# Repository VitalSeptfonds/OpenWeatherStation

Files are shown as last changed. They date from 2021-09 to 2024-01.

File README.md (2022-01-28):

# OpenWeatherStation

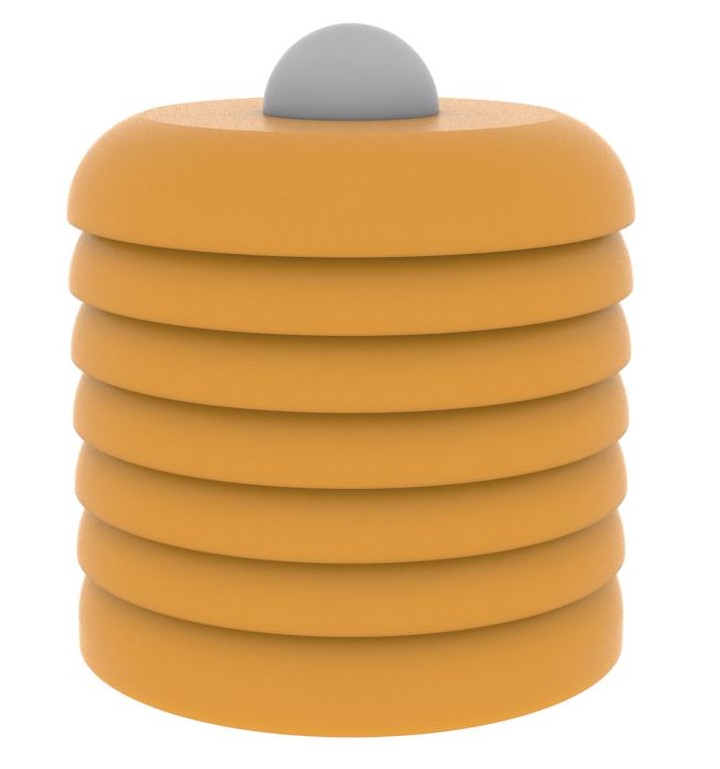
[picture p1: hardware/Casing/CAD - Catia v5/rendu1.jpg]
Test Image


## The Project
The main goal is to create an Open Weather Station based on STM32.
This weather station will give access to real time data through an Web API.

### Main Functionality 
- POE : Power Over Ethernet
- 3D printable 
- Ingress Protection : IP33
  - Protected from tools and wires greater than 2.5 millimeters
  - Protected from water spray less than 60 degrees from vertical
- Real time data
- Sensors :
  - Temperature
  - Humidity
  - Pressure
  - Light

## API
### Request
`GET /get_data/`

Return Real Time Data

### Response

    {
      "time" : "01/01/01 00:00:00",
      "data" :
        {
          "temperature" : 20.00,
          "humidity" : 50,
          "pressure" : 1013,
          "light" : 3000
        }

    }

## Error handling

Error responses should include a common HTTP status code, message for the developer, message for the end-user (when appropriate), internal error code

    {
      "error" :
        {
          "status" : 400,
          "errorCode" : "444444",
          "errorMessage" : "Verbose, plain language description of the problem. Provide developers
           suggestions about how to solve their problems here",
          "userMessage" : "This is a message that can be passed along to end-users, if needed."
         }
    }

Use three simple, common response codes :

* 400 - Bad Request
* 404 - Not Found
* 500 - Internal Server Error

## Links
* [Hardware](hardware/readme.md)
* [Software](software/readme.md)

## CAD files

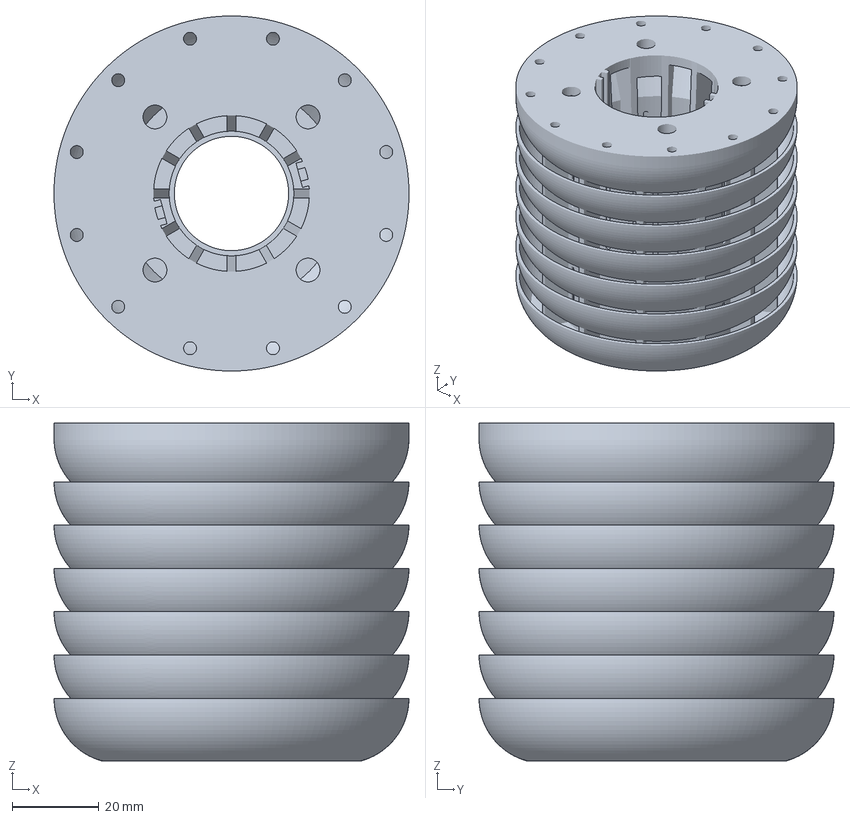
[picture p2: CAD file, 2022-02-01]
hardware/Casing/3D Printing Setup/MainCase.3mf
82.0 x 82.0 x 78.0 mm

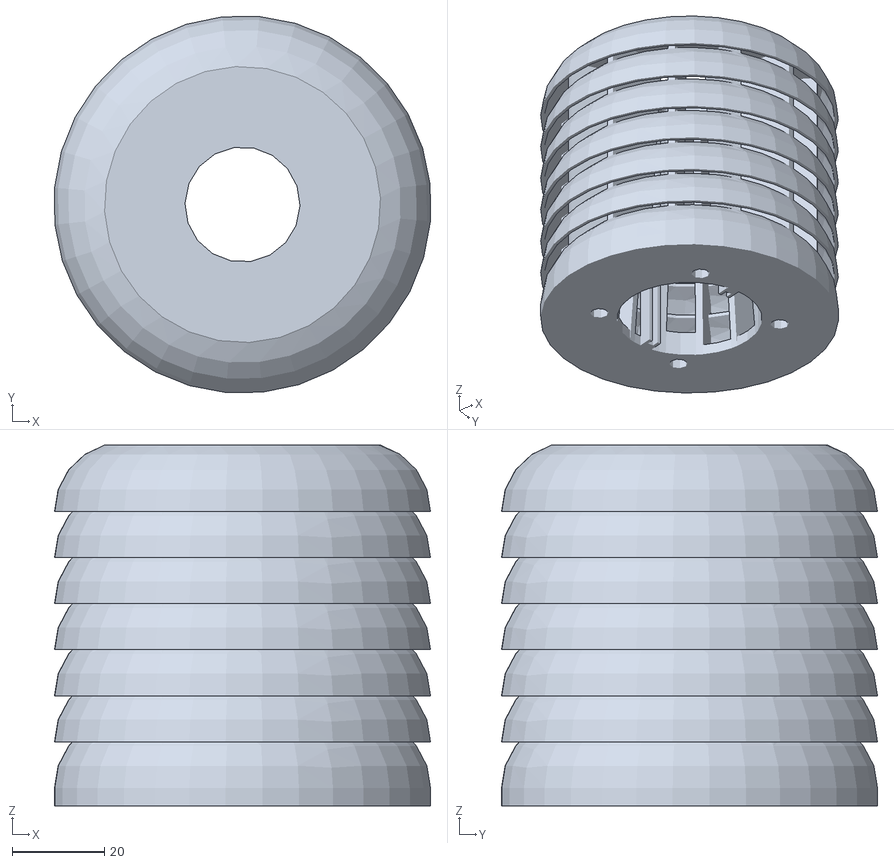
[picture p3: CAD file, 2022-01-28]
hardware/Casing/STL/MainCase.stl
81.7 x 81.7 x 78.4

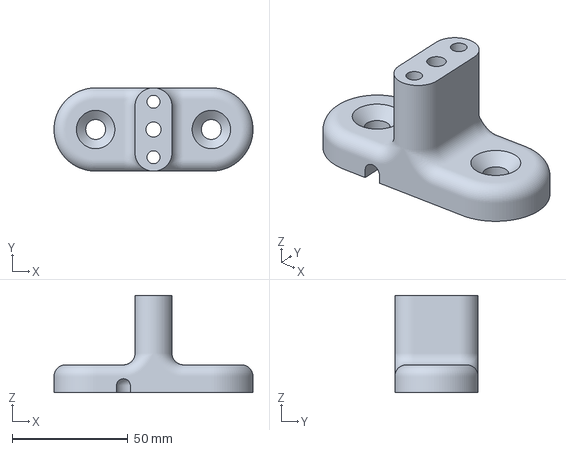
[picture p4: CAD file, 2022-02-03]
hardware/Casing/3D Printing Setup/wall_arm.3mf
86.0 x 36.0 x 42.0 mm

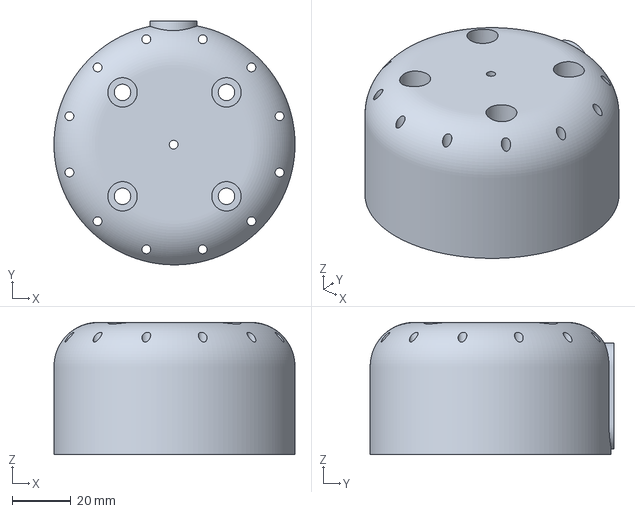
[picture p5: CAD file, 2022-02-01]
hardware/Casing/3D Printing Setup/Wall_Support.3mf
82.0 x 82.9 x 45.0 mm

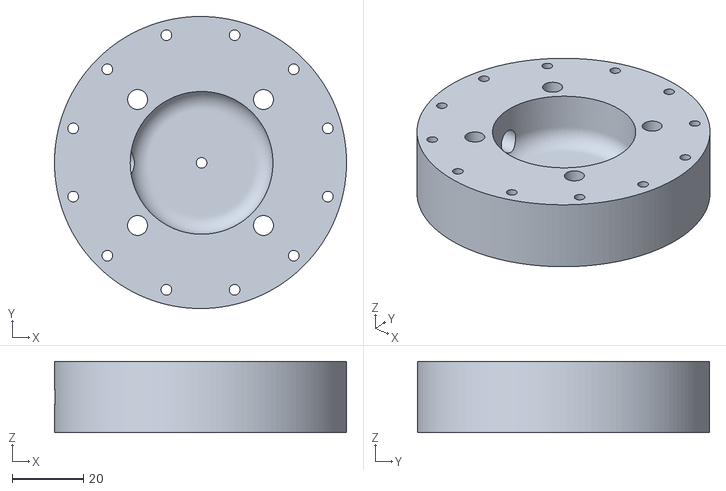
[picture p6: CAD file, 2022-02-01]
hardware/Casing/STL/socle.stl
82.0 x 82.0 x 20.0

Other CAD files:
hardware/Casing/STL/wall_arm.stl
hardware/Casing/3D Printing Setup/socle.3mf
hardware/Casing/STL/Wall_Support.stl
hardware/Casing/CAD - Catia v5/BH1750.CATPart
hardware/Casing/CAD - Catia v5/MainAssembly.CATProduct
hardware/Casing/CAD - Catia v5/MainCase.CATPart
hardware/Casing/CAD - Catia v5/PCB.CATPart
hardware/Casing/CAD - Catia v5/Wall_Support.CATPart
hardware/Casing/CAD - Catia v5/socle.CATPart
hardware/Casing/CAD - Catia v5/wall_arm.CATPart

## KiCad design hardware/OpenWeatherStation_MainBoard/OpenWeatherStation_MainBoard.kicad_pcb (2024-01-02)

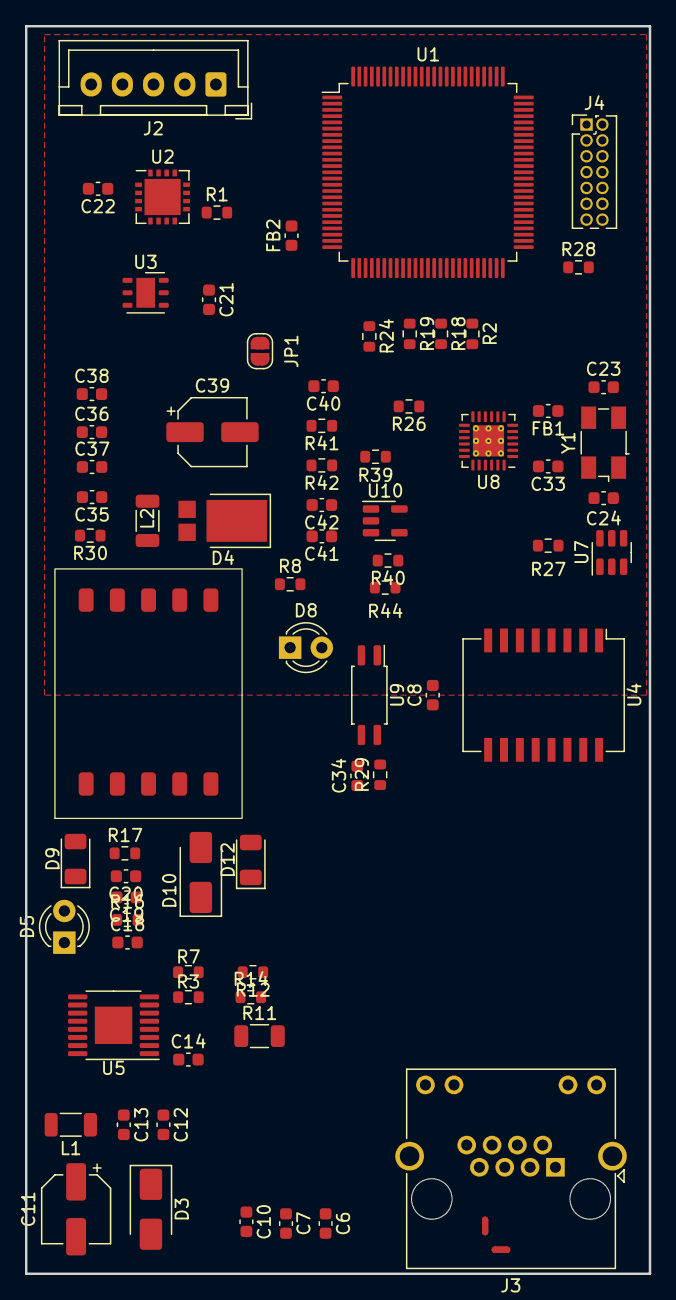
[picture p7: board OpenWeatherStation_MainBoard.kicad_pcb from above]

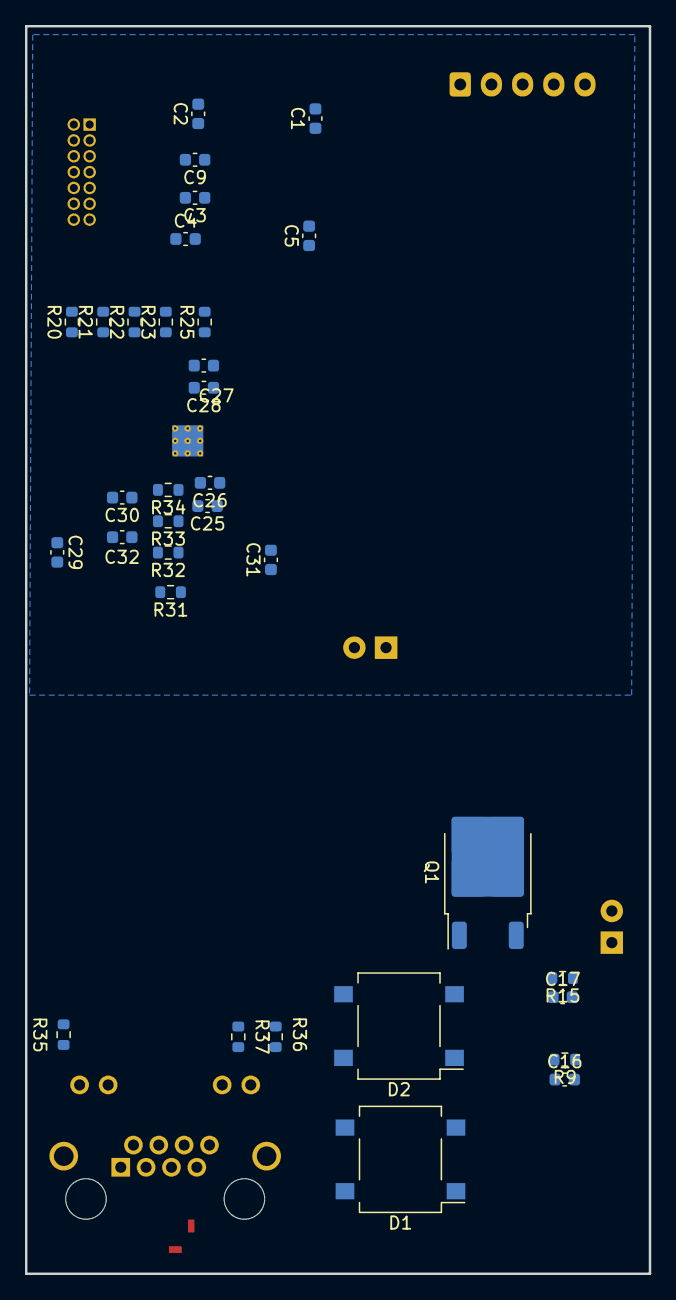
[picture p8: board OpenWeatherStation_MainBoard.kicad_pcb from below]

Board: 2 copper layers, 50.0 x 100.0 mm, 111 parts (33 on the bottom side), 85 nets, no tracks yet.

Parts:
C1, C2, C3, C4, C5, C9, C10, C12, C13, C16, C19, C21, C22, C25, C28, C29, C30, C31, C32: 100nF; C_0603_1608Metric
C6, C14: 1nF; C_0603_1608Metric
C7, C20, C26, C34, C40, C41: 1uF; C_0603_1608Metric
C8: 2.2nF; C_0603_1608Metric
C11: 22uF; CP_Elec_5x3
C17, C18, C27: 470pF; C_0603_1608Metric
C23, C24: 30pF; C_0603_1608Metric
C33: 10uF; C_0603_1608Metric
C35: 560pF; C_0603_1608Metric
C36, C37, C38: 22uF; C_0603_1608Metric
C39: 330uF; CP_Elec_5x3
C42: 22nF; C_0603_1608Metric
D1, D2: DF01S1; Diode_Bridge_OnSemi_SDIP-4L
D3, D10: SMAJ58A; D_SMA
D4: D_Schottky; D_PowerDI-5
D5, D8: LED; LED_D3.0mm
D9, D12: D_Schottky; D_1206_3216Metric
FB1, FB2: FerriteBead; C_0603_1608Metric
J2: Conn_01x05_Pin; JST_XH_B5B-XH-A_1x05_P2.50mm_Vertical
J3: RJ45_LED_Shielded; RJ45_Amphenol_RJHSE538X
J4: Conn_02x07_Odd_Even; PinHeader_2x07_P1.27mm_Vertical
JP1: SolderJumper_2_Open; SolderJumper-2_P1.3mm_Open_RoundedPad1.0x1.5mm
L1, L2: L; L_1206_3216Metric
NT1, NT2, NT3, NT4: NetTie_2; NetTie-2_SMD_Pad0.5mm
Q1: Q_NMOS_GDS; TO-252-2
R1, R8: 1k; R_0603_1608Metric
R2, R18, R19, R24: 33R; R_0603_1608Metric
R3: 158R; R_0603_1608Metric
R7: 22k; R_0603_1608Metric
R9: 124k; R_0603_1608Metric
R11: 0.33R; R_1206_3216Metric
R12: 0.33R; R_0603_1608Metric
R14, R20, R21, R22, R25, R26, R29, R37: 10k; R_0603_1608Metric
R15, R28: 100R; R_0603_1608Metric
R16: 4k7; R_0603_1608Metric
R17, R41: 10R; R_0603_1608Metric
R23: 1k5; R_0603_1608Metric
R27: 12k1; R_0603_1608Metric
R30: 4R7; R_0603_1608Metric
R31, R32, R33, R34: 50R; R_0603_1608Metric
R35, R36: 270R; R_0603_1608Metric
R39: 21k; R_0603_1608Metric
R40: 12k4; R_0603_1608Metric
R42: 390R; R_0603_1608Metric
R44: 3k3; R_0603_1608Metric
U1: STM32F107VCTx; LQFP-100_14x14mm_P0.5mm
U2: FXPS7115D4; Panasonic_HQFN-16-1EP_4x4mm_P0.65mm_EP2.9x2.9mm
U3: HTU21D; DFN-6-1EP_3x3mm_P1mm_EP1.5x2.4mm
U4: Transformer_Ethernet_Wuerth_749013011A
U5: PM8800A; HTSSOP-16-1EP_4.4x5mm_P0.65mm_EP3x3mm
U6: POE13P-33L; SM13117EL
U7: USBLC6-4SC6; SOT-23-6
U8: LAN8742A; VQFN-24-1EP_4x4mm_P0.5mm_EP2.5x2.5mm_ThermalVias
U9: TCMT1107; SOP-4_4.4x2.6mm_P1.27mm
U10: TL431DBV; SOT-23-5
Y1: Crystal; Crystal_SMD_Abracon_ABM3B-4Pin_5.0x3.2mm

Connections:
+3.3VA: FB2.2, U1.21 (VREF+), U1.22 (VDDA)
+3V3: C1.1, C2.1, C3.1, C4.1, C5.1, C9.1, C21.1, C22.1, C28.1, FB1.2, FB2.1, J2.1, J4.3, R1.1, R20.2, R21.2, R22.2, R23.2, R25.2, U1.6 (VBAT), U1.11 (VDD), U1.28 (VDD), U1.50 (VDD), U1.75 (VDD), U1.100 (VDD), U2.1 (VCC), U2.13 (Vccio), U2.16 (VCC), U3.5 (VDD), U8.9 (VDDIO)
/Connectors/ETH_PORT1: J3.1, U4.16 (TX1+)
/Connectors/ETH_PORT2: J3.2, U4.14 (TX1-)
/Connectors/ETH_PORT3: J3.3, U4.11 (TX2+)
/Connectors/ETH_PORT4: J3.4, NT1.1
/Connectors/ETH_PORT5: J3.5, NT2.1
/Connectors/ETH_PORT6: J3.6, U4.9 (TX2-)
/Connectors/ETH_PORT7: J3.7, NT3.1
/Connectors/ETH_PORT8: J3.8, NT4.1
/Connectors/ETH_STATUS.LED_GREEN: J3.12, R37.1, U8.2 (LED2/~INTSEL)
/Connectors/ETH_STATUS.LED_YELLOW: J3.10, U8.3 (LED1/REGOFF)
/Connectors/I2C.SCL: J2.2, U1.92 (PB6), U2.9 (SCLK/SCL), U3.6 (SCL)
/Connectors/I2C.SDA: J2.3, U1.93 (PB7), U2.11 (MISO/SDA), U3.1 (SDA)
/Connectors/NRST: J4.12, U1.14 (NRST), U8.15 (~RST)
/Connectors/SWD.SWCLK: J4.6, U1.76 (PA14)
/Connectors/SWD.SWDIO: J4.4, U1.72 (PA13)
/Connectors/SWD.SWO: J4.8, U1.89 (PB3)
/Connectors/VCP.RX: J4.13, U1.69 (PA10)
/Connectors/VCP.TX: J4.14, U1.68 (PA9)
/Ethernet/ETH.CRC_DV: R19.1, U1.32 (PA7)
/Ethernet/ETH.MDC: U1.16 (PC1), U8.13 (MDC)
/Ethernet/ETH.MDIO: R23.1, U1.25 (PA2), U8.12 (MDIO)
/Ethernet/ETH.REF_CLK: R24.1, U1.24 (PA1)
/Ethernet/ETH.RXD0: R2.1, U1.33 (PC4)
/Ethernet/ETH.RXD1: R18.1, U1.34 (PC5)
/Ethernet/ETH.TXD0: U1.51 (PB12), U8.17 (TXD0)
/Ethernet/ETH.TXD1: U1.52 (PB13), U8.18 (TXD1)
/Ethernet/ETH.TX_EN: U1.48 (PB11), U8.16 (TXEN)
/Ethernet/ETH_DATA.CT: C25.1, C29.1, C30.1, C31.1, C32.1, C33.1, FB1.1, R31.1, R32.1, R33.1, R34.1, U4.2 (CT1), U4.7 (CT2), U7.5 (VBUS), U8.1 (VDD2A), U8.19 (VDD1A)
/Ethernet/ETH_DATA.RD+: R32.2, U4.6 (TD2+), U7.1 (I/O1), U8.23 (RXP)
/Ethernet/ETH_DATA.RD-: R31.2, U4.8 (TD2-), U7.6 (I/O4), U8.22 (RXN)
/Ethernet/ETH_DATA.TD+: R34.2, U4.1 (TD1+), U7.3 (I/O2), U8.21 (TXP)
/Ethernet/ETH_DATA.TD-: R33.2, U4.3 (TD1-), U7.4 (I/O3), U8.20 (TXN)
/PoE/VIN: C6.1, C7.1, C10.1, C11.1, D1.1 (+), D2.1 (+), D3.1 (A1), L1.1, U5.4 (VIN)
/PoE/VSS: C6.2, C7.2, C10.2, C14.1, D1.2 (-), D2.2 (-), D3.2 (A2), R3.2, R7.2, U5.8 (VSS)
GND: C1.2, C2.2, C3.2, C4.2, C5.2, C8.2, C9.2, C21.2, C22.2, C23.2, C24.2, C25.2, C26.2, C27.1, C28.2, C29.2, C30.2, C31.2, C32.2, C33.2, C40.1, J2.4, J2.5, J3.SH, J4.5, J4.7, R26.2, R27.2, R28.1, R35.1, R36.1, R37.2, R40.2, U1.10 (VSS), U1.19 (VSSA), U1.27 (VSS), U1.49 (VSS), U1.74 (VSS), U1.99 (VSS), U2.4 (VSS), U2.15 (VSS), U2.17 (PAD), U3.2 (GND), U7.2 (GND), U8.25 (VSS), U10.5 (A)
GNDA: C16.2, C18.2, C19.2, C34.2, R9.1, U5.15 (VFB), U5.16 (AGND), U6.2, U9.3
GNDPWR: C8.1, C11.2, C12.2, C13.2, C14.2, C17.2, C20.2, R11.1, R14.1, U5.9 (GND)
unnamed: C34.1, R29.1
unnamed: C35.1, R30.1
unnamed: C40.2, R41.1, U9.1
unnamed: C42.1, R44.1
unnamed: D1.3, NT3.2, NT4.2
unnamed: D1.4, NT1.2, NT2.2
unnamed: D2.3, U4.15 (CT1)
unnamed: D2.4, U4.10 (CT2)
unnamed: D4.2 (A), R30.2, U6.7, U6.8
unnamed: C35.2, C36.2, C37.2, D4.1 (K), L2.1
unnamed: D5.2 (A), R16.1
unnamed: C18.1, D5.1 (K), U5.12 (nPGD)
unnamed: D8.2 (A), R8.2
unnamed: C36.1, C37.1, C38.1, C39.2, D8.1 (K), U6.9, U6.10
unnamed: D9.2 (A), R17.1
unnamed: C19.1, C20.1, D9.1 (K), R16.2, U5.11 (VCC)
unnamed: D10.1 (A1), D12.1 (K)
unnamed: D10.2 (A2), Q1.2 (D), U6.4
unnamed: C12.1, C13.1, D12.2 (A), L1.2, U6.3
unnamed: J3.9, R35.2
unnamed: J3.11, R36.2
unnamed: J4.11, R28.2
unnamed: C38.2, C39.1, JP1.1 (A), L2.2, R8.1, R39.1, R41.2
unnamed: Q1.1 (G), R12.1, R14.2
unnamed: Q1.3 (S), R11.2, R15.1
unnamed: R17.2, U6.1
unnamed: R42.1, U9.2
unnamed: R1.2, U2.8 (SS_B)
unnamed: R29.2, U5.14 (COMP), U9.4
unnamed: C17.1, R15.2, U5.13 (CS)
unnamed: R7.1, U5.7 (DCCL)
unnamed: R12.2, U5.10 (GD)
unnamed: R3.1, U5.5 (RCLASS)
unnamed: R9.2, U5.1 (RT)
unnamed: C16.1, U5.2 (SS)
unnamed: R19.2, R22.1, U8.11 (CRS_DV/MODE2)
unnamed: R27.1, U8.24 (RBIAS)
unnamed: R2.2, R20.1, U8.8 (RXD0/MODE0)
unnamed: R18.2, R21.1, U8.7 (RXD1/MODE1)
unnamed: R26.1, U8.10 (RXER/PHYAD0)
unnamed: C26.1, C27.2, U8.6 (VDDCR)
unnamed: C23.1, U8.5 (XTAL1/CLKIN), Y1.2
unnamed: C24.1, U8.4 (XTAL2), Y1.1
unnamed: R24.2, R25.1, U8.14 (~INT/REFCLKO)
unnamed: C41.2, C42.2, R42.2, U10.3 (K)
unnamed: C41.1, R39.2, R40.1, R44.2, U10.4 (REF)

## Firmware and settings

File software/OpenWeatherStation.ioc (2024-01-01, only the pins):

Mcu.UserName=STM32F107RCTx
PA1.Signal=ETH_REF_CLK
PA10.Signal=USART1_RX
PA13.Signal=SYS_JTMS-SWDIO
PA14.Signal=SYS_JTCK-SWCLK
PA2.Signal=ETH_MDIO
PA7.Signal=ETH_CRS_DV
PA9.Signal=USART1_TX
PB11.Signal=ETH_TX_EN
PB12.Signal=ETH_TXD0
PB13.Signal=ETH_TXD1
PB3.Signal=SYS_TRACESWO
PB6.Signal=I2C1_SCL
PB7.Signal=I2C1_SDA
PC1.Signal=ETH_MDC
PC4.Signal=ETH_RXD0
PC5.Signal=ETH_RXD1

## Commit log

2021-09-14 add kicad project
    [OpenWheatherStation.kicad_pcb, OpenWheatherStation.sch]
2021-09-14 add stm32 project
2021-09-14 add casing catia main assembly file
    [MainAssembly.CATProduct]
2021-09-18 CAD : add light sensor and main part of the casing
    [BH1750.CATPart, MainCase.CATPart]
2021-09-18 design main case, work in progress
    [MainAssembly.CATProduct, MainCase.CATPart]
2021-09-18 add cad rendering
2021-09-21 fix name issue
    [OpenWeatherStation_MainBoard.kicad_pcb, OpenWeatherStation_MainBoard.sch]
2022-01-28 update mechanical design
    [PCB.CATPart, socle.CATPart]
2022-01-28 add production setup and files for casing
    [MainCase.3mf, MainCase.stl, socle.3mf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]
2022-01-29 update main part design
    [MainCase.CATPart]
2022-01-29 improve Water resistance of casing
    [MainAssembly.CATProduct, socle.CATPart]
2022-01-29 update casing, add wall support ,update production setup
    [MainAssembly.CATProduct, MainCase.3mf, Wall_Support.3mf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]
2022-02-01 adjust hole size and stl mesh size, new production files
    [MainAssembly.CATProduct, MainCase.3mf, Wall_Support.3mf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]
2022-02-03 fix screew lenght
    [wall_arm.3mf, wall_arm.CATPart, wall_arm.stl]
2022-03-27 update doc and schematic
    [OpenWeatherStation_MainBoard.kicad_pcb, OpenWeatherStation_MainBoard.kicad_sch, OpenWeatherStation_MainBoard.sch]
2022-10-24 update schematic
    [OpenWeatherStation_MainBoard.kicad_sch, actuators.kicad_sch, ethernet.kicad_sch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]
2023-06-18 electronic design wip : sensors and connectors : done
    [OpenWeatherStation_MainBoard.kicad_sch, PoE.kicad_sch, connectors.kicad_sch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]
2023-06-19 poe design wip
    [untitled.kicad_sch]
2023-12-31 update board schematics (sensors, ethernet ...)
    [ethernet.kicad_sch, sensors.kicad_sch, uC.kicad_sch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]
2023-12-31 update stm32 cube ide version
2023-12-31 fix hierarchical bus
    [OpenWeatherStation_MainBoard.kicad_sch, connectors.kicad_sch, ethernet.kicad_sch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]
2023-12-31 elec save
    [untitled.kicad_sch]
2023-12-31 update pcb kicad version
    [OpenWeatherStation_MainBoard.kicad_pcb]
2023-12-31 Create nucleo f676.pdf
    add nucleo board schematic for ethernet implementation example
2023-12-31 move eth connector to dedicated sheet
    [OpenWeatherStation_MainBoard.kicad_sch, connectors.kicad_sch, untitled.kicad_sch]
2024-01-01 poe wip
    [untitled.kicad_sch]
2024-01-01 update schematics
    [connectors.kicad_sch, untitled.kicad_sch]
2024-01-01 add swd with trace and uart comm
2024-01-01 schematic update
    [OpenWeatherStation_MainBoard.kicad_sch, connectors.kicad_sch, ethernet.kicad_sch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]
2024-01-01 minor schematic update
    [untitled.kicad_sch]
2024-01-01 Delete an4415-power-over-ethernetpd-converter-with-33-v-3-a-output-standard-ieee-8023af-compliant-stmicroelectronics (1).pdf
    rm doc duplicate
2024-01-01 electrical design wip
    [OpenWeatherStation_MainBoard.kicad_pcb, OpenWeatherStation_MainBoard.kicad_sch, connectors.kicad_sch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]
2024-01-02 update elec
    [connectors.kicad_sch, ethernet.kicad_sch, sensors.kicad_sch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]
2024-01-02 udpate pcb design
    [OpenWeatherStation_MainBoard.kicad_pcb, connectors.kicad_sch, ethernet.kicad_sch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]
2024-01-02 update pcb
    [OpenWeatherStation_MainBoard.kicad_pcb, untitled.kicad_sch]
2024-01-02 modif 3d casing
    [MainAssembly.CATProduct, PCB.CATPart]
2024-01-02 update 3d
    [MainAssembly.CATProduct]
